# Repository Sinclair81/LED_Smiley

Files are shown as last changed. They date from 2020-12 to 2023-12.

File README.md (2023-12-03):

# LED Smiley PCB #



<!-- markdownlint-disable MD033 -->
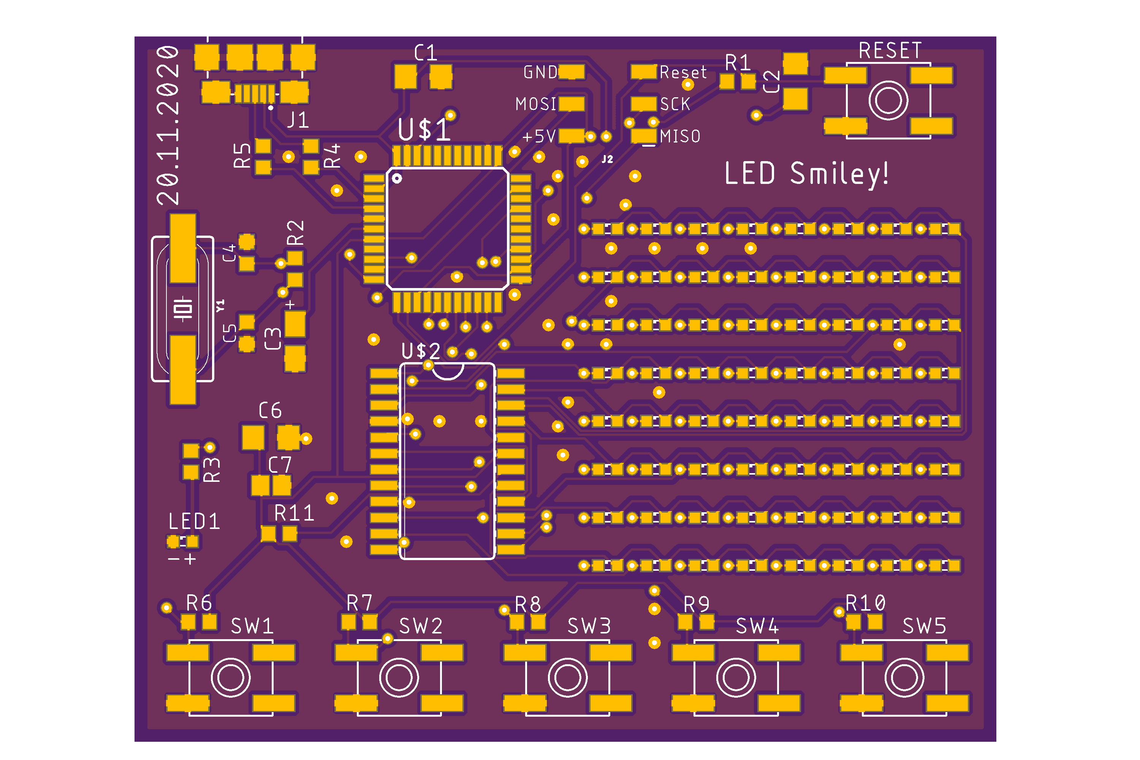
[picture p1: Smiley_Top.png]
Smiley_Top


<!-- https://raw.githubusercontent.com/Sinclair81/LED_Smiley/master/Smiley_Top.png -->

<!-- markdownlint-enable MD033 -->

A [Arduino](https://www.arduino.cc) [Leonardo](https://store.arduino.cc/arduino-leonardo-with-headers) like PCB with 65 LED's and 5 Buttons.  
MCU - ATmega32U4-AU (16MHz)  
LED Driver - Max7219CWG  
  
The main parts of the library code are from:  
[LedControl.h](http://wayoda.github.io/LedControl/) Copyright (c) 2007 Eberhard Fahle  
[LedMatrix.h](https://github.com/agr00m/LedMatrix) Copyright (c) 2015 Aaron Groom  
[Button.h (v1)](https://github.com/madleech/Button) Copyright (c) 2016 Michael D K Adams  
[Button.h (v2)](https://github.com/davidepalladino/Button-Arduino) Copyright (c) 2021 Davide Palladino  
  
Name            | Pin
--------------- | ---------------------
Button 1        | D0  
Button 2        | D1  
Button 3        | D2  
Button 4        | D3  
Button 5        | D4  
Max7219CWG LOAD | D10  
Max7219CWG CLK  | D11  
Max7219CWG DIN  | D12  
LED 1           | D13  
LED 2 to LED 65 | Max7219CWG

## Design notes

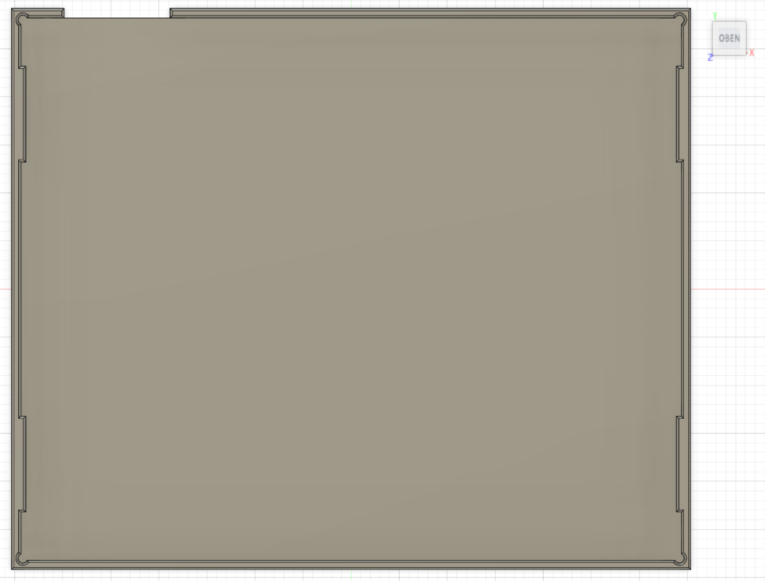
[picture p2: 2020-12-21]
Back_Cover_img_2.png

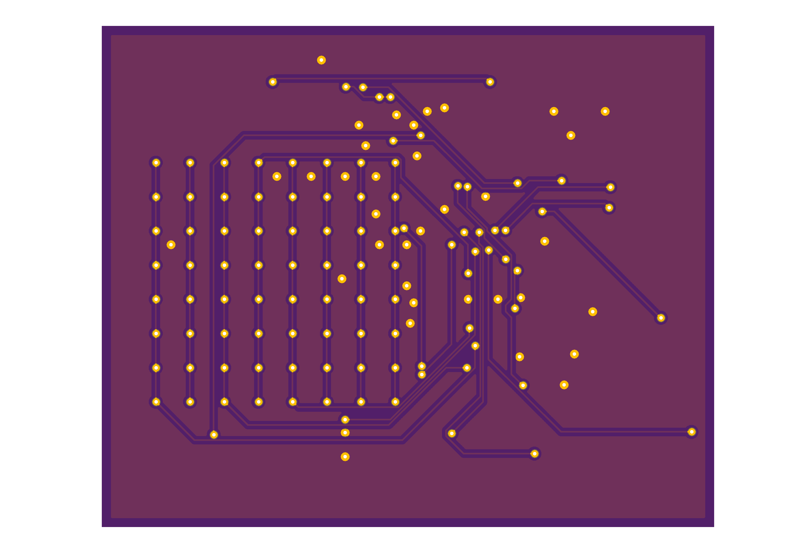
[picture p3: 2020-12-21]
Smiley_Bootom.png

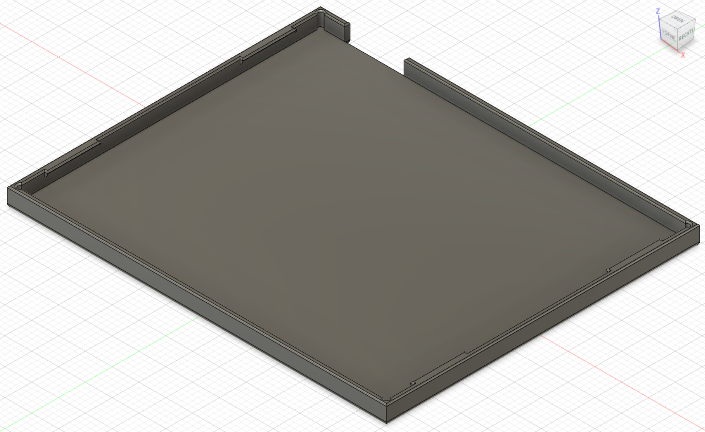
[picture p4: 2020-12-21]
Back_Cover_img_1.png

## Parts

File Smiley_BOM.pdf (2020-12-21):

### Smiley PCB

Qty | Parts | Value | Package | Device
65 | LED1, LD1, LD2, LD3, LD4, LD5, LD6, LD7, LD8, LD9, LD10, LD11, LD12, LD13, LD14, LD15, LD16, LD17, LD18, LD19, LD20, LD21, LD22, LD23, LD24, LD25, LD26, LD27, LD28, LD29, LD30, LD31, LD32, LD33, LD34, LD35, LD36, LD37, LD38, LD39, LD40, LD41, LD42, LD43, LD44, LD45, LD46, LD47, LD48, LD49, LD50, LD51, LD52, LD53, LD54, LD55, LD56, LD57, LD58, LD59, LD60, LD61, LD62, LD63, LD64 2V, 25mA | | SML0603 | LEDSML0603 | RND 135-00181 - SMD-LED Rot 632nm 0603 120mcd 25mA | distrelec.at
3 | C1, C2, C6 | 100nF | C1206 | C-USC1206 | Keramikkondensator 100nF, 50VDC, 1206, ±10 % | distrelec.at
1 | C3 | 1uF | A/3216-18R | CPOL-USA/3216-18R | TPS 3216 1,0/20 | reichelt.at
2 | C4, C5 | 22pF | C0603K | C-USC0603K | KEM C0G0603 22P | reichelt.at
1 | C7 | 10uF | C0805 | C-USC0805 | Keramikkondensator 10uF, 16VDC, 0805, ±10 % | distrelec.at
7 | R1, R6, R7, R8, R9, R10, R11 | 10k | R0603 | R-US_R0603 | SMD-Widerstand 100mW, 10kOhm, 1 %, 0603 | distrelec.at
1 | R2 | 1M | R0603 | R-US_R0603 | VIS CRCW06031M0 | reichelt.at
1 | R3 | 12k | R0603 | R-US_R0603 | SMD-0603 12K | reichelt.at
2 | R4, R5 | 22 | R0603 | R-US_R0603 | SMD-0603 22 | reichelt.at
1 | Y1 | 16MHz | HC49UP | CRYSTALSMD-HC49UP | LFXTAL003237 - Quarz SMD 16MHz, IQD | distrelec.at
1 | U$1 | ATMEGA32U4-AU | TQFP44 | ATMEGA32U4-AU | ATMEGA32U4-AU - AVR RISC Mikrocontroller Flash 32kB TQFP, Microchip | distrelec.at
1 | U$2 | MAX7219CWG | SO24L | MAX7219CWG | MAX 7219 CWG | reichelt.at
6 | RESET, SW1, SW2, SW3, SW4, SW5 | SPST_TACT-EVQQ2 | EVQ-Q2 | SPST_TACT-EVQQ2 | Kurzhubtaster B3FS, 1 Schliesser, 0.98N, 6 x 6mm | distrelec.at
1 | J1 | 10118192-0002LF | 10118192-0002LF | 10118192-0002LF | 10118192-0001LF - Micro USB, Micro USB-B 2.0 Buchse | distrelec.at
1 | | | | | Smiley_PCB | PCBWay.com

1

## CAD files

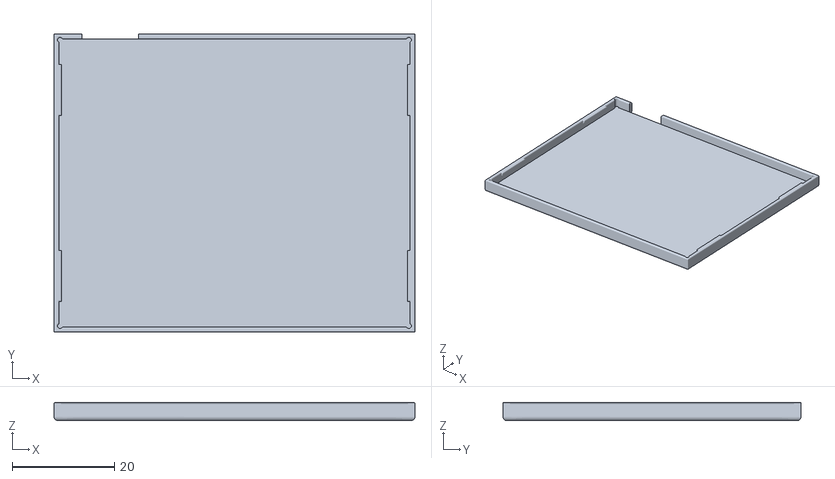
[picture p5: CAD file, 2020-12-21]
Back_Cover.stl
70.7 x 58.4 x 3.60

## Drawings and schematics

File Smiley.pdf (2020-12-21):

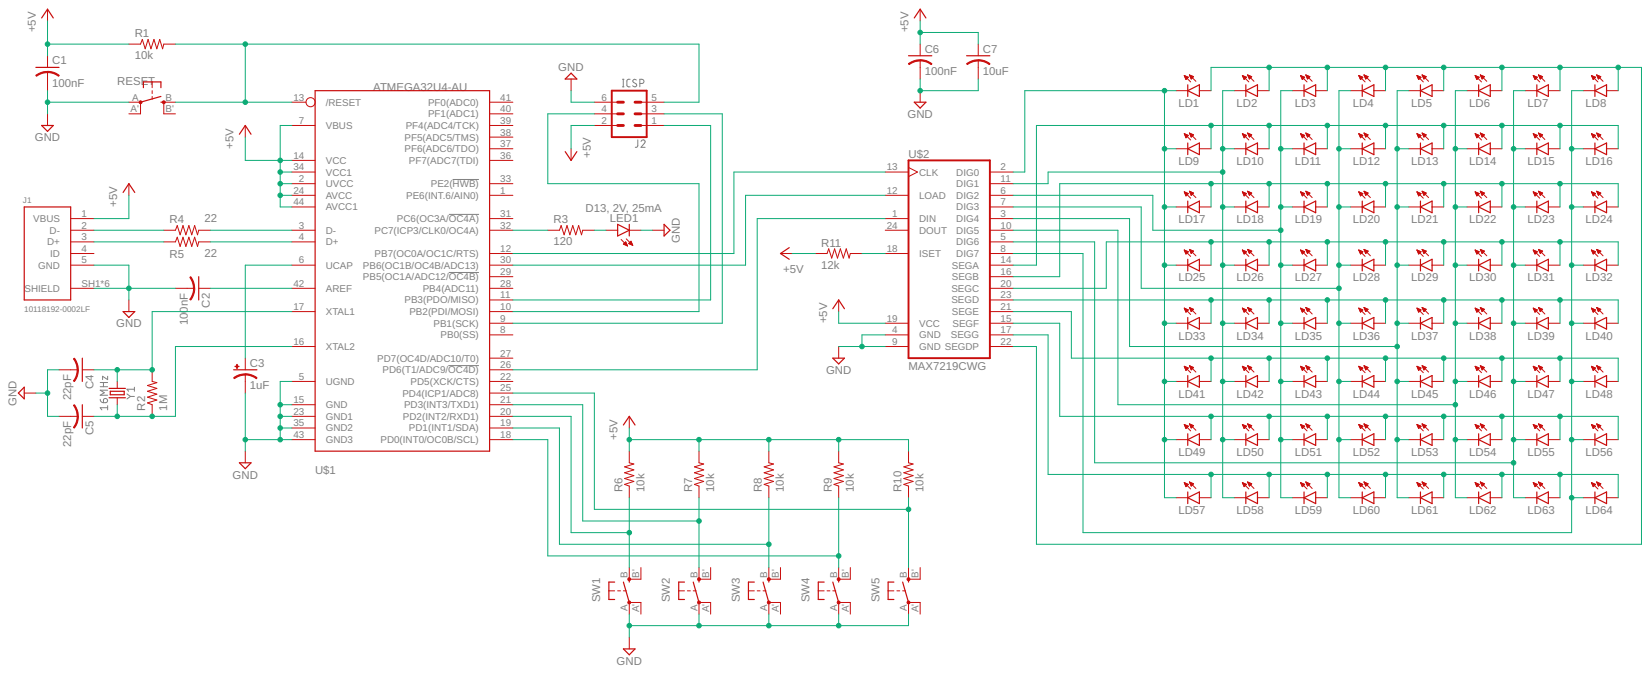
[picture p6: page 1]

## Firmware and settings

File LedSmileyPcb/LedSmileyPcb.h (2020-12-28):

/*    
 *    Approx. 80% of the LED code are from:
 * 
 *    LedControl.h - A library for controling Leds with a MAX7219/MAX7221
 *    Copyright (c) 2007 Eberhard Fahle
 *    http://wayoda.github.io/LedControl/
 * 
 *    AND:
 * 
 *    LedMatrix.h - An Arduino library for led dot matrix using MAX72XX drivers
 *    Copyright (c) 2015 Aaron Groom
 *    https://github.com/agr00m/LedMatrix
 * 
 * 
 *    100% of the Button code are from:
 * 
 *    Button.h - a small library for Arduino to handle button debouncing
 *    Copyright (C) 2016 Michael D K Adams
 *    https://github.com/madleech/Button
 * 
 */

#ifndef LED_SMILEY_PCB_h
#define LED_SMILEY_PCB_h

#include <avr/pgmspace.h>

#if (ARDUINO >= 100)
#include <Arduino.h>
#else
#include <WProgram.h>
#endif

#include "font_5x7_row.h"
#include "font_8x8_row.h"

#define FONT5x7 5
#define FONT8x8 8

#define BUTTON_1_PIN 0
#define BUTTON_2_PIN 1
#define BUTTON_3_PIN 2
#define BUTTON_4_PIN 3
#define BUTTON_5_PIN 4 // 7 for Interrupt ??? pcb v2 ???

#define INTERRUPT_1_PIN 0
#define INTERRUPT_2_PIN 1
#define INTERRUPT_3_PIN 2
#define INTERRUPT_4_PIN 3
#define INTERRUPT_5_PIN 7


class LedSmileyPcb {
    private :
        /* The array for shifting the data to the devices */
        byte spidata[16];
        /* Send out a single command to the device */
        void spiTransfer(byte opcode, byte data);

        /* We keep track of the led-status in this array */
        byte status[8];
        /* Data is shifted out of this pin*/
        int SPI_MOSI;
        /* The clock is signaled on this pin */
        int SPI_CLK;
        /* This one is driven LOW for chip selectzion */
        int SPI_CS;
        /* Character read buffer */
        uint8_t charBuffer[8];
        /* Scroll delay */
        int sDelay;
        /* Current font width */
        uint8_t font;

        /* 
         * Shifts all the leds in a single display row one position to the left.
         * Params :
         */
        void shiftLeft(); 

        void bufferChar(uint8_t c);      

    public:
        /* 
         * Create a new controler 
         * Params :
         * dataPin		pin on the Arduino where data gets shifted out (D12)
         * clockPin		pin for the clock                              (D11)
         * csPin		pin for selecting the device                   (D10)
         */
        LedSmileyPcb(int dataPin = 12, int clkPin = 11, int csPin = 10);

        /* 
         * Set the shutdown (power saving) mode for the device
         * Params :
         * addr	The address of the display to control
         * status	If true the device goes into power-down mode. Set to false
         *		for normal operation.
         */
        void shutdown(bool status);

        /* 
         * Set the number of digits (or rows) to be displayed.
         * See datasheet for sideeffects of the scanlimit on the brightness
         * of the display.
         * Params :
         * limit	number of digits to be displayed (1..8)
         */
        void setScanLimit(int limit);

        /* 
         * Set the brightness of the display.
         * Params:
         * intensity	the brightness of the display. (0..15)
         */
        void setIntensity(int intensity);

        /* 
         * Switch all Leds on the display off. 
         * Params:
         */
        void clearDisplay();

        /* 
         * Updates the display.
         */
        void update(void);

        /* 
         * Sets the font to display
         * Params:
         * font        Font to display (5x7 or 8x8)
         */
        void setFont(uint8_t newFont);

        /* 
         * Get the char lenght from font
         */
        int getFontLengh();

        /* 
         * Set the status of a single Led.
         * Params :
         * row	        the row of the Led (0..7)
         * col	        the column of the Led (0..7)
         * state	    If true the led is switched on, if false it is switched off
         */
        void setLed(int row, int col, boolean state);

        /* 
         * Set all 8 Led's in a column to a new state
         * Params:
         * col	column which is to be set (0..7)
         * value	each bit set to 1 will light up the
         *		corresponding Led.
         */
        void setColumn(int col, byte value);

        /* 
         * Set all 8 Led's in a row to a new state
         * Params:
         * row	row which is to be set (0..7)
         * value	each bit set to 1 will light up the
         *		corresponding Led.
         */
        void setRow(int row, byte value);

        /* 
         * Sets the delay time, in miliseconds, for scrolling text.
         * Params:   
         * val       Delay time
         */
        void scrollDelay(int val);

        /* 
         * Prints a single character.
         * Params:
         * c           Character to draw
         */
        void printChar(char c);
        
        /* 
         * Prints a single character.
         * Params:
         * c           Character to draw
         * x           X coordinate of the top left corner
         * y           Y coordinate of the top left corner
         */
        void printChar(char c, uint8_t x, uint8_t y);
        
        /* 
         * Scrolls a single character onto the matrix from the right to left
         * Params:
         * c           Character to scroll
        */
        void scrollChar(uint8_t c);

        /* 
         * Scrolls a single character onto the matrix from the right to left
         * Params:
         * c            Character to scroll
         * col          Position for scrolling
        */
        void scrollChar(uint8_t c, uint8_t col);

};


// https://github.com/madleech/Button
class Button {
	public:
		Button(uint8_t pin, uint16_t debounce_ms = 30);
		void begin();
		bool read();
		bool toggled();
		bool pressed();
		bool released();
		bool has_changed();
		
		const static bool PRESSED = LOW;
		const static bool RELEASED = HIGH;
	
	private:
		uint8_t  _pin;
		uint16_t _delay;
		bool     _state;
		uint32_t _ignore_until;
		bool     _has_changed;
};

#endif	//LedSmileyPcb.h

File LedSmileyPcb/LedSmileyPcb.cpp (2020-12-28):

/*    
 *    Approx. 80% of the LED code are from:
 * 
 *    LedControl.h - A library for controling Leds with a MAX7219/MAX7221
 *    Copyright (c) 2007 Eberhard Fahle
 *    http://wayoda.github.io/LedControl/
 * 
 *    AND:
 * 
 *    LedMatrix.h - An Arduino library for led dot matrix using MAX72XX drivers
 *    Copyright (c) 2015 Aaron Groom
 *    https://github.com/agr00m/LedMatrix
 * 
 * 
 *    100% of the Button code are from:
 * 
 *    Button.h - a small library for Arduino to handle button debouncing
 *    Copyright (C) 2016 Michael D K Adams
 *    https://github.com/madleech/Button
 * 
 */

#include "LedSmileyPcb.h"

//the opcodes for the MAX7219
#define OP_NOOP   0
#define OP_DECODEMODE  9
#define OP_INTENSITY   10
#define OP_SCANLIMIT   11
#define OP_SHUTDOWN    12
#define OP_DISPLAYTEST 15

#define SETBIT(ADDRESS,BIT)   (ADDRESS |= (1<<BIT))
#define CLEARBIT(ADDRESS,BIT) (ADDRESS &= ~(1<<BIT))
#define CHECKBIT(ADDRESS,BIT) (ADDRESS & (1<<BIT))

LedSmileyPcb::LedSmileyPcb(int dataPin, int clkPin, int csPin) {
    SPI_MOSI=dataPin;
    SPI_CLK=clkPin;
    SPI_CS=csPin;
    pinMode(SPI_MOSI,OUTPUT);
    pinMode(SPI_CLK,OUTPUT);
    pinMode(SPI_CS,OUTPUT);
    digitalWrite(SPI_CS,HIGH);
    for(int i=0;i<8;i++) {
        status[i]=0x00;
    }
    spiTransfer(OP_DISPLAYTEST,0);
    //scanlimit is set to max on startup
    setScanLimit(7);
    //decode is done in source
    spiTransfer(OP_DECODEMODE,0);
    clearDisplay();
    //we go into shutdown-mode on startup
    shutdown(true);
    // Set the default scroll delay
    sDelay = 100;
    // Set the default font to 8x8
    font = FONT8x8;
}

void LedSmileyPcb::shutdown(bool b) {
    if (b) {
        spiTransfer(OP_SHUTDOWN,0);
    } else {
        spiTransfer(OP_SHUTDOWN,1);
    }
}

void LedSmileyPcb::setScanLimit(int limit) {
    if (limit>=0 && limit<8) {
        spiTransfer(OP_SCANLIMIT,limit);
    }
}

void LedSmileyPcb::setIntensity(int intensity) {
    if (intensity>=0 && intensity<16) {
        spiTransfer(OP_INTENSITY,intensity);
    }
}

void LedSmileyPcb::clearDisplay() {
    for (int i=0;i<8;i++) {
        status[i]=0;
        spiTransfer(i+1,status[i]);
    }
}

void LedSmileyPcb::setFont(uint8_t newFont) {
   if (newFont != FONT5x7 && newFont != FONT8x8) {
      return;
   }
   font = newFont;
}

int LedSmileyPcb::getFontLengh() {
    if (font == FONT5x7) {
        return 7;
    }
    return 8;
}

void LedSmileyPcb::setLed(int row, int column, boolean state) {
    byte val=0x00;
    if (row<0 || row>7 || column<0 || column>7) {
        return;
    }
    val=B10000000 >> column;
    if (state) {
        status[row]=status[row]|val;
    } else {
        val=~val;
        status[row]=status[row]&val;
    }
    spiTransfer(row+1,status[row]);
}

void LedSmileyPcb::setColumn(int col, byte value) {
    if(col<0 || col>7) {
        return;
    }
    status[col]=value;
    spiTransfer(col+1,status[col]);
}

void LedSmileyPcb::setRow(int row, byte value) {
    byte val;
    if(row<0 || row>7) {
        return;
    }
    for (int col=0;col<8;col++) {
        val=value >> (7-col);
        val=val & 0x01;
        setLed(col,row,val);
    }
}

void LedSmileyPcb::scrollDelay(int val) {
	sDelay = val;
}

void LedSmileyPcb::printChar(char c) {
    if (font == FONT5x7) {
        printChar(c, 0, 1);
    } else if (font == FONT8x8) {
        printChar(c, 0, 0);
    }
}

void LedSmileyPcb::printChar(char c, uint8_t x, uint8_t y) {
    int8_t fHeight, rows, offset; 
    bufferChar(c);
    for (uint8_t col = 0; col < font; col++) { 
        if (x+col >= 0 && x+col < 8) {
            if (font == FONT5x7) {
                rows = 7;
                offset = 1;
            } else if (font == FONT8x8) {
                rows = 8;
                offset = 0;
            }
            for (uint8_t row = 0; row < rows; row++) {
                if (y+row >= 0 && y+row < 8) {
                setLed(x+col, y+row, CHECKBIT(charBuffer[col], 7-row-offset));
                }
            }
        }
    }
}

void LedSmileyPcb::scrollChar(uint8_t c) {
    bufferChar(c);
    for (uint8_t col = 0; col < font; col++) {
        shiftLeft();
        status[7] = charBuffer[col];
        update();
    }
    // If 5x7 font, shift one more to add a space between characters.
    if (font == FONT5x7) {
        shiftLeft();
        update();
    }
}

void LedSmileyPcb::scrollChar(uint8_t c, uint8_t col) { 
    bufferChar(c);
    shiftLeft();
    status[7] = charBuffer[col];
    update();
    // If 5x7 font, shift one more to add a space between characters.
    if ((font == FONT5x7) & (col == 7)) {
        shiftLeft();
        update();
    }
}

void LedSmileyPcb::shiftLeft() {
    for (byte col = 0; col < 8; col++) {
        if (col > 0) {
            status[col-1] = status[col];
        }
    }
    status[7] = 0;
    delay(sDelay);
}

void LedSmileyPcb::bufferChar(uint8_t c) { 
   for (uint8_t row = 0; row < font; row++) {  
      if (font == FONT5x7) {
        charBuffer[row] = pgm_read_byte(&font_5x7_row[c][row]);
      } else if (font == FONT8x8) {
        charBuffer[row] = pgm_read_byte(&font_8x8_row[c][row]);
      }
   }
}

void LedSmileyPcb::update(void) {
    for (int i=0;i<8;i++) {
        spiTransfer(i+1,status[i]);
    }
}

void LedSmileyPcb::spiTransfer(volatile byte opcode, volatile byte data) {
    //Create an array with the data to shift out
    for (int i=0;i<8;i++) {
        spidata[i]=(byte)0;
    }
    //put our device data into the array
    spidata[1]=opcode;
    spidata[0]=data;
    //enable the line 
    digitalWrite(SPI_CS,LOW);
    //Now shift out the data 
    for (int i=8;i>0;i--) {
        shiftOut(SPI_MOSI,SPI_CLK,MSBFIRST,spidata[i-1]);
    }
    //latch the data onto the display
    digitalWrite(SPI_CS,HIGH);
}


/***************************************************************************************
 *                                                                                     *
 *          Button Code !!!                                                            *
 *          https://github.com/madleech/Button                                         *
 *                                                                                     *
 ***************************************************************************************/

Button::Button(uint8_t pin, uint16_t debounce_ms): _pin(pin), _delay(debounce_ms), _state(HIGH), _ignore_until(0), _has_changed(false) {
}

void Button::begin() {
	pinMode(_pin, INPUT);
}

bool Button::read() {
	// ignore pin changes until after this delay time
	if (_ignore_until > millis()) {
		// ignore any changes during this period
	} else if (digitalRead(_pin) != _state) {// pin has changed 
		_ignore_until = millis() + _delay;
		_state = !_state;
		_has_changed = true;
	}
	return _state;
}

// has the button been toggled from on -> off, or vice versa
bool Button::toggled() {
	read();
	return has_changed();
}
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

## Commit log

2020-12-21 add GerberFiles and BOM
2023-12-03 Button v2
